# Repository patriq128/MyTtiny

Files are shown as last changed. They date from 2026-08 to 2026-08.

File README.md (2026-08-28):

# MyTtiny

My own development board based on the **ATtiny3217** microcontroller.

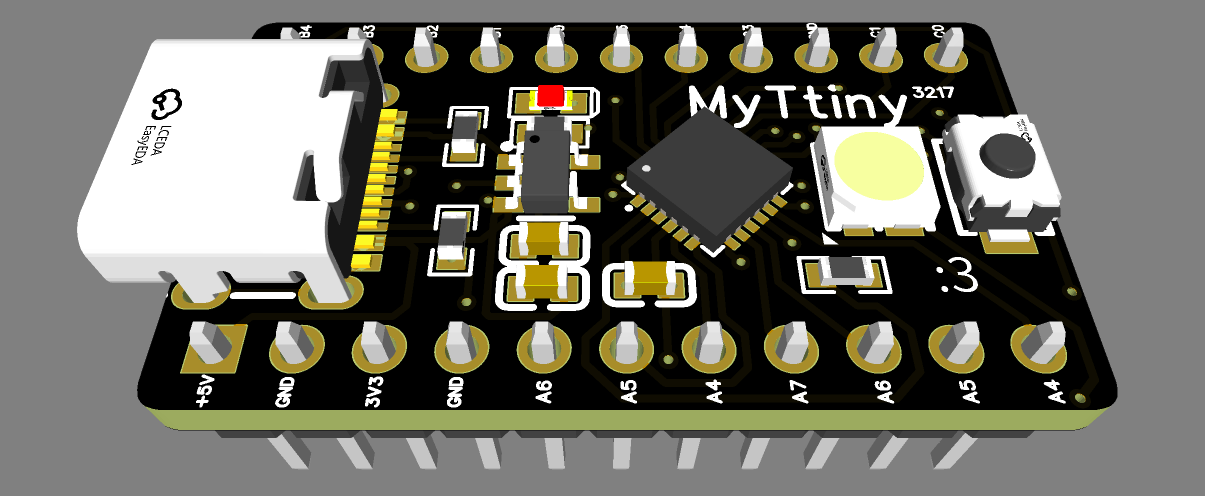
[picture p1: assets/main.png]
MyTtiny development board


## Features

One of the main reasons I made this board was for my own projects. However, I also wanted to make it useful enough for other people to use.

- **Compact size**

  I tried to make this board as small as possible, and I think I did a pretty good job. The board measures only **29.718 × 17.018 mm**.

- **USB-C**

  The board uses a USB-C connector, making it easy to power, program, and communicate with. I also included the required configuration resistors, so **USB-C to USB-C cables work properly**.

- **UART**

  I decided to add a **CH340N** USB-to-UART converter. This allows the board to communicate with a computer through USB and makes it possible to upload programs and use a serial monitor.

- **NeoPixel LED**

  I wanted the board to provide visual feedback without requiring any external hardware, so I added a programmable RGB LED.

- **Labeled Pins**

  Every header pin is labeled on both the top and bottom sides of the PCB, making it easier to identify the pins regardless of which side of the board you are looking at.

## Hardware

  ### Microcontroller

  For this board, I decided to use the **ATtiny3217**. It is small, power-efficient, and capable enough for a wide range of simple embedded projects.

  ### USB Interface

  The board uses a USB-C connector. I chose USB-C because it is compact, modern, and convenient to use.

  I also added a USB protection chip to help protect the USB data lines from electrical faults.

  The USB interface is connected to a **CH340N** USB-to-UART converter, which provides serial communication between the computer and the ATtiny3217.

  ### Power

  There are two voltage levels available on the board:

  - **5V** — Supplied by the USB-C connector or the 5V pin header. It is regulated down to 3.3V using an **AP2112K** voltage regulator.
  - **3.3V** — This is the main operating voltage of the board.

  I also added a small red LED to indicate when the board is powered.

  ### NeoPixel LED

  The board includes an **SK6812MINI** programmable RGB LED. It can be controlled by the ATtiny3217 and used to display different colors or provide visual feedback.

  ### Button

  There is also a small user button that can be used for any purpose in your code.

## Programming

  ### Bootloader

  Before uploading your first program, you need to install a bootloader on the ATtiny3217.

  The bootloader can be uploaded using the **three UPDI pins** located at the bottom of the board.

  For this project, I am using the bootloader provided by **[MegaTinyCore](https://github.com/SpenceKonde/megaTinyCore)**.

  ### Uploading Programs

  Once the bootloader is installed, you can upload programs and use the serial monitor through the USB-C port connected to the **CH340N** USB-to-UART converter.

## Pinout

The name of every pin is printed on both the top and bottom sides of the PCB.

> **Note:** On the top side, the pins are labeled without the **"P"** prefix.

### Official Pinout Image

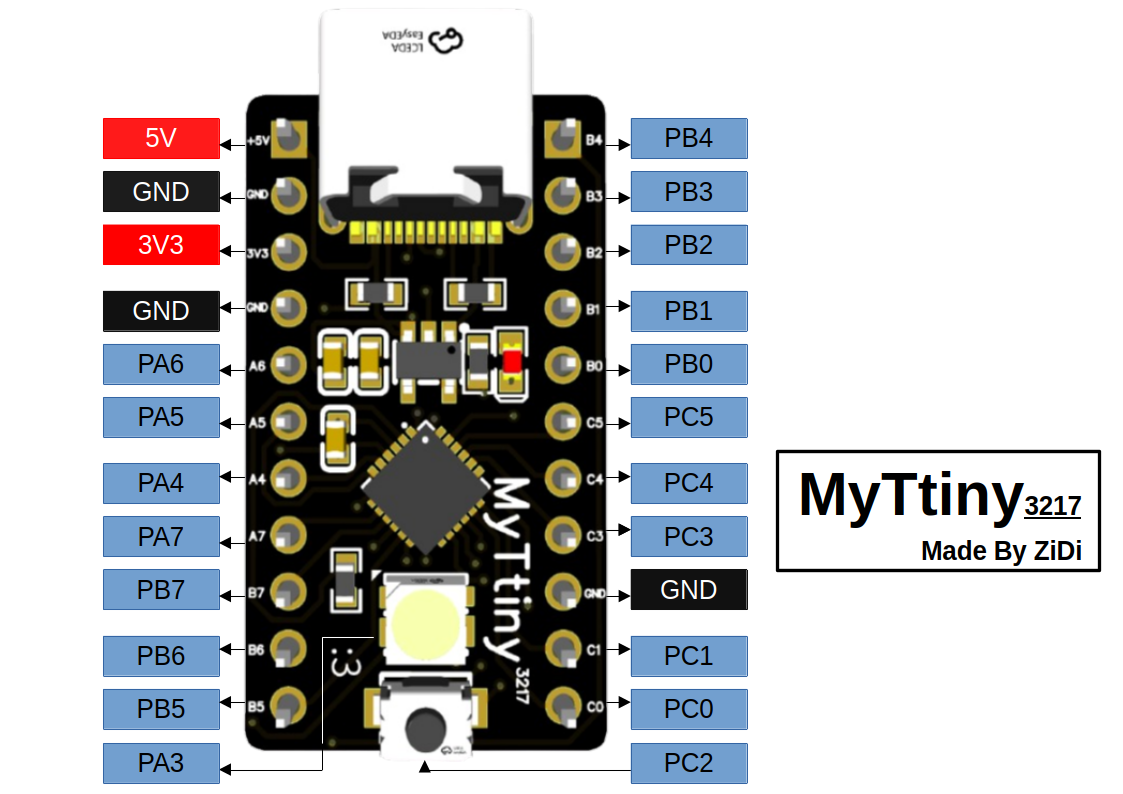
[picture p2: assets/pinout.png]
MyTtiny pinout


## Board

  ### Schematic

  I tried to make the schematic as clean and easy to understand as possible.

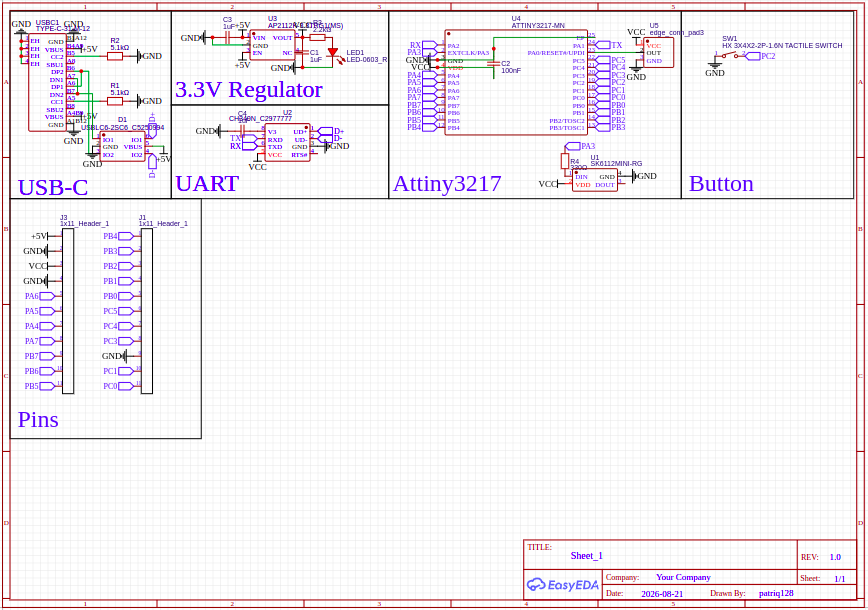
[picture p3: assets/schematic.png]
MyTtiny schematic
  

  ### PCB

  #### Top

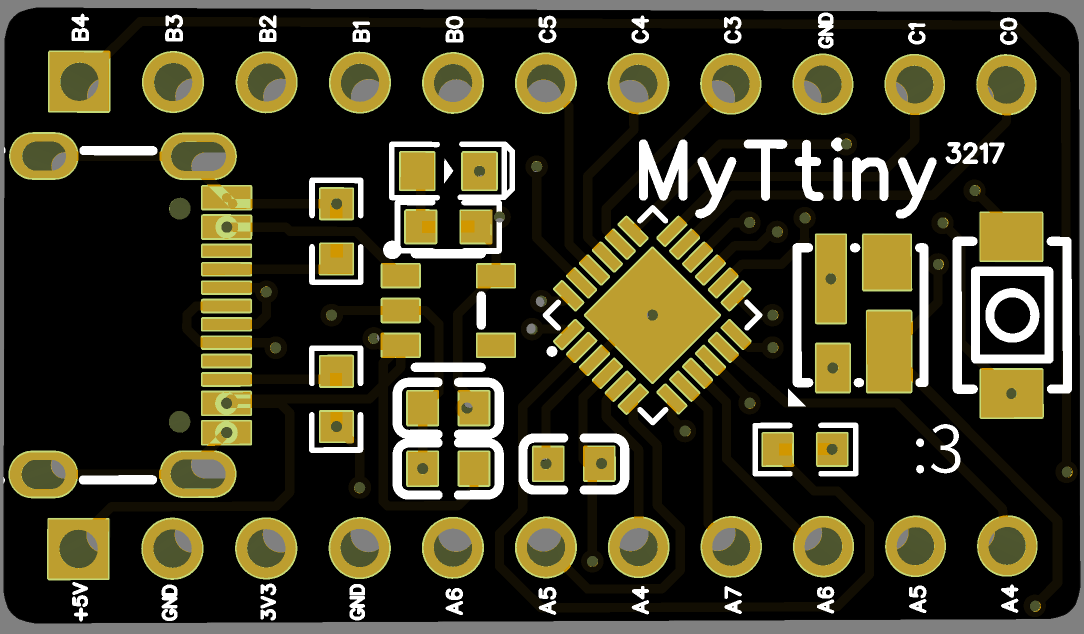
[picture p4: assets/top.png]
MyTtiny PCB top side
  

  #### Bottom

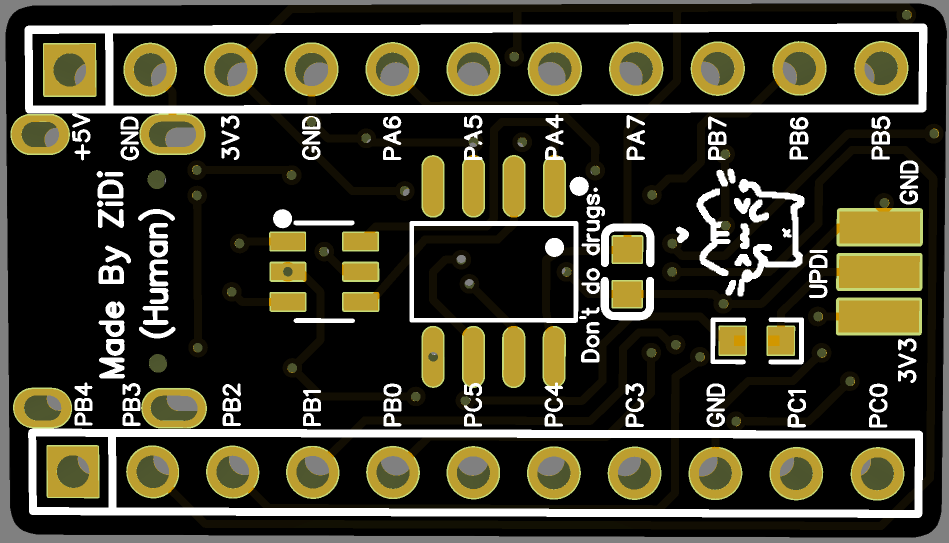
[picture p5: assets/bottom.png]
MyTtiny PCB bottom side
  

## Production

The main goal of this project is to have the board manufactured. I plan to have it manufactured by **JLCPCB**, which will manufacture the PCBs and assemble the components for me.

In the [`production`](production/) folder, you can find:

- **Gerber files**
- **Pick-and-place file**
- **BOM file**

## Why I Made This

Honestly, I originally made this board because I was bored.

I also didn't really want to use some of the existing development boards available to me, so I decided to design my own.

I chose the **ATtiny3217** as the main microcontroller because I wanted to try something different instead of using more common chips such as the RP2040 or ESP32.

In the end, it became a small development board that I can use for my own projects while also making the design available for anyone else who might find it useful.

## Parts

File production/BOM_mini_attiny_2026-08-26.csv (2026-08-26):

ID | Name | Designator | Footprint | Quantity | Manufacturer Part | Manufacturer | Supplier | Supplier Part | Price
1 | 1uF | C4,C1,C3 | C0603 | 3 | 06033D105MAT2A | Kyocera AVX | LCSC | C597124 | 0.027
2 | USBLC6-2SC6_C5250994 | D1 | SOT-23-6_L2.9-W1.6-P0.95-LS2.8-BL | 1 | USBLC6-2SC6 | TWGMC(迪嘉) | LCSC | C5250994 | 0.091
3 | CH340N_C2977777 | U2 | SOP-8_L4.9-W3.9-P1.27-LS6.0-BL | 1 | CH340N | WCH(南京沁恒) | LCSC | C2977777 | 0.679
4 | edge_conn_pad3 | U5 | PADPAD4X1.5 3PAD_SIGNALS | 1
5 | 2011-1X11G00SB | H1,H2 | HDR-TH_11P-P2.54_2011-1X11G00SB | 2 | 2011-1X11G00SB | WingTAT(格林柏) | LCSC | C49569634 | 0.051
6 | 1kΩ | R5 | R0603 | 1 | RMC 0603 1K J N | Tyohm(幸亚电阻) | LCSC | C5362357 | 0.003
7 | HX 3X4X2-2P-1.6N TACTILE SWITCH | SW1 | KEY-SMD_L4.0-W3.0-LS4.9-1 | 1 | HX 3x4x2-2P-1.6N TACTILE SWITCH | hanxia(韩下) | LCSC | C49234124 | 0.026
8 | 100nF | C2 | C0603 | 1 | 06033C104K4T2A | Kyocera AVX | LCSC | C597114 | 0.025
9 | LED-0603_R | LED1 | LED0603_RED | 1 | 19-217/R6C-AL1M2VY/3T | EVERLIGHT(台湾亿光) | LCSC | C72044 | 0.021
10 | 5.1kΩ | R1,R2 | R0603 | 2 | HoAR0603-1/10W-5.1KR-0.1%-TCR25 | Milliohm(毫欧) | LCSC | C5123587 | 0.073
11 | 2.2kΩ | R3 | R0603 | 1 | RMC06032.2K1%N | Tyohm(幸亚电阻) | LCSC | C325591 | 0.004
12 | 330Ω | R4 | R0603 | 1 | 0603WAD3300T5E | UNI-ROYAL(厚声) | LCSC | C407595 | 0.005
13 | SK6112MINI-RG | U1 | LED-SMD_4P-L3.7-W3.5-SK6812SMINI-001 | 1 | SK6112MINI-RG | 欧思科光电 | LCSC | C5440781 | 0.15
14 | AP2112K-3.3TRG1(MS) | U3 | SOT-23-5_L2.9-W1.6-P0.95-LS2.7-BR | 1 | AP2112K-3.3TRG1(MS) | MSKSEMI(美森科) | LCSC | C22365427 | 0.079
15 | ATTINY3217-MN | U4 | HVQFN-24_L4.0-W4.0-P0.50-BL-EP2.6 | 1 | ATTINY3217-MN | MICROCHIP(美国微芯) | LCSC | C1340454 | 2.304
16 | TYPE-C-31-M-12 | USBC1 | USB-C_SMD-TYPE-C-31-M-12_1 | 1 | TYPE-C-31-M-12 | 韩国韩荣 | LCSC | C165948 | 0.187

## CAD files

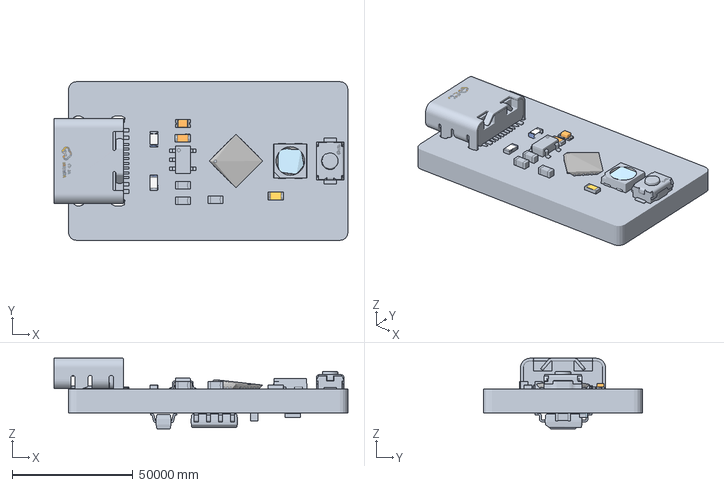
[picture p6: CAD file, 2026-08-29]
CAD/PCB.step
121780.9 x 65799.8 x 29243.7 mm

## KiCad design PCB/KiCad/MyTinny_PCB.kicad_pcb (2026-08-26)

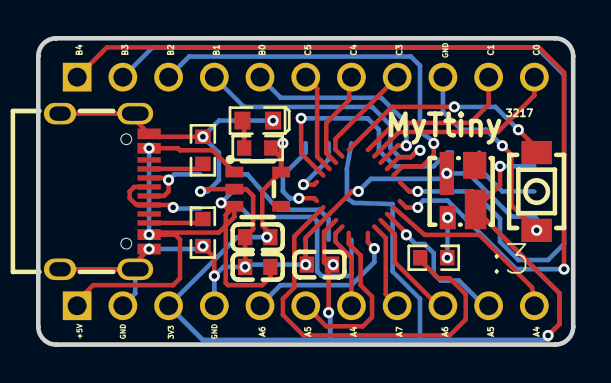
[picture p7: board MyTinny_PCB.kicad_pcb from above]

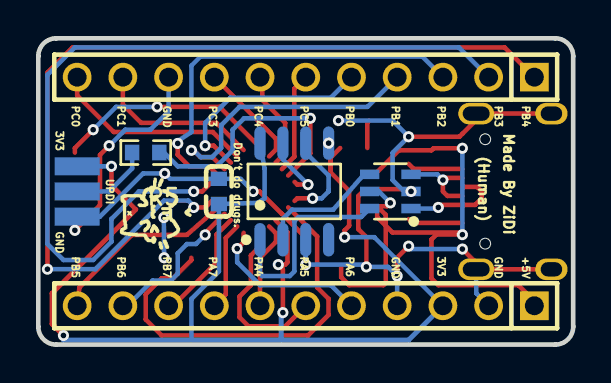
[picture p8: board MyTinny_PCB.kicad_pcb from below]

Board: 2 copper layers, 29.7 x 17.0 mm, 19 parts (7 on the bottom side), 12 nets.

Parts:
C1, C3, C4: 1uF; C0603
C2: 100nF; C0603
D1: USBLC6-2SC6_C5250994; SOT-23-6_L2.9-W1.6-P0.95-LS2.8-BL
H1, H2: 2011-1X11G00SB; HDR-TH_11P-P2.54_2011-1X11G00SB
LED1: LED-0603_R; LED0603_RED
R1, R2: 5.1kΩ; R0603
R3: 2.2kΩ; R0603
R4: 330Ω; R0603
R5: 1kΩ; R0603
SW1: HX 3X4X2-2P-1.6N TACTILE SWITCH; KEY-SMD_L4.0-W3.0-LS4.9-1
U1: SK6112MINI-RG; LED-SMD_4P-L3.7-W3.5-SK6812SMINI-001
U2: CH340N_C2977777; SOP-8_L4.9-W3.9-P1.27-LS6.0-BL
U3: AP2112K-3.3TRG1(MS); SOT-23-5_L2.9-W1.6-P0.95-LS2.7-BR
U5: edge_conn_pad3; PADPAD4X1.5 3PAD_SIGNALS
USBC1: TYPE-C-31-M-12; USB-C_SMD-TYPE-C-31-M-12_1

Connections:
+5V: C3.2, D1.5, H1.1, U3.1, U3.3, USBC1.A4B9, USBC1.B4A9
D+: D1.6, U2.1
D-: D1.4, U2.2
GND: C1.1, C2.2, C3.1, C4.1, D1.2, H1.2, H1.4, H2.9, LED1.2, R1.1, R2.1, SW1.1, U1.4, U2.3, U3.2, U5.3, USBC1.1, USBC1.2, USBC1.3, USBC1.4, USBC1.A1B12, USBC1.B1A12
R1_2: R1.2, USBC1.A5
R2_2: R2.2, USBC1.B5
R3_2: LED1.1, R3.2
R4_1: R4.1, U1.1
U5_2: R5.2, U5.2
USBC1_A6: D1.1, USBC1.A6, USBC1.B6
USBC1_B7: D1.3, USBC1.A7, USBC1.B7
VCC: C1.2, C2.1, C4.2, H1.3, R3.1, U1.2, U2.5, U2.8, U3.5, U5.1
